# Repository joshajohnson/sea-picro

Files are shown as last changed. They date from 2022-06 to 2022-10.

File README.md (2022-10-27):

# Sea-Picro

Sea-Picro is a RP2040 based board in the Arduino Pro Micro form factor. Like [Sea-Micro](https://github.com/joshajohnson/sea-micro#sea-micro), it's designed to be a drop in replacement for keyboards wanting an upgrade from ATmega32u4 based pro micros.

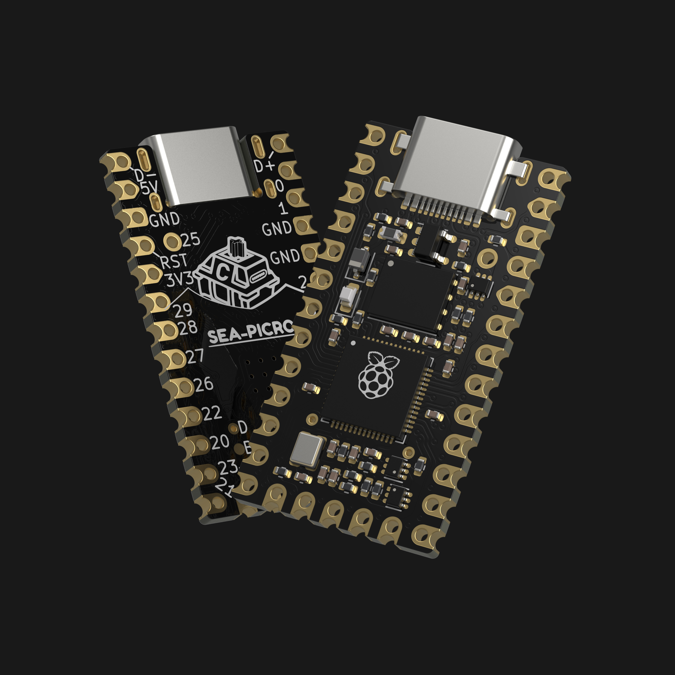
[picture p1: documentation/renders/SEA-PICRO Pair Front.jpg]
pcb render


There are two variants:
- EXT, featuring an Elite-C pinout, with dedicated 5V RGB LED pin, but without a reset button.
- RST, featuring a pro micro pinout, with onboard RGB LED and reset button.

Sea-Picro can be purchased from [CustomKBD](https://customkbd.com/).

### Sea-Picro EXT
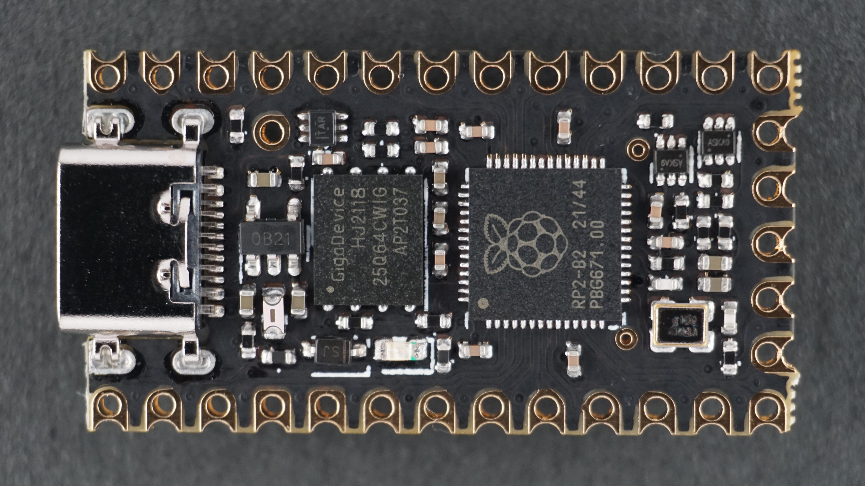
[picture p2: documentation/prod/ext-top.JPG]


### Sea-Picro RST
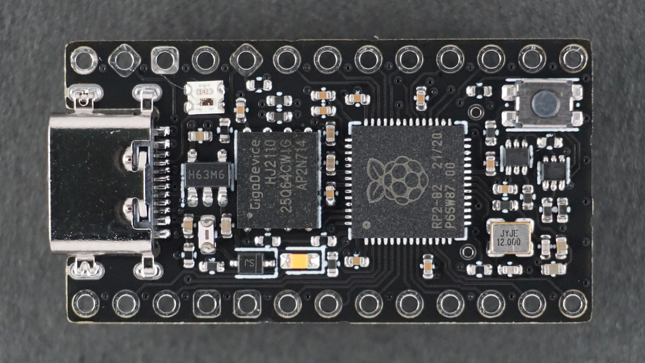
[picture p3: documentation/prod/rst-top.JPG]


## Features
- Compatiable with most pro micro based keyboards
- RP2040 microcontroller, with dual M0+ processors at up to 133MHz
- Mid mount USB-C connector, which is low profile and can't be ripped off
- Optional [Elite-C](https://deskthority.net/wiki/Elite-C) style pinout, adding an additional 5 IO for large keyboards
- Single button reset / bootloader circuit which changes behavior based on how long it's held (RP2040 usually requires two buttons to flash new firmware, making it challenging when installed upside down in a keyboard)
- ROM bootloader which prevents board from being bricked
- EXT version has a 5V level shifter and extra pin to drive strings of WS2812 LEDs.
- RST version has a WS2812 LED for use with CircuitPython or as a status indicator on the RST version. 
- Onboard power LED.
- IO pinout identical to the [Sparkfun RP2040 Pro Micro](https://www.sparkfun.com/products/18288)

## Pinout
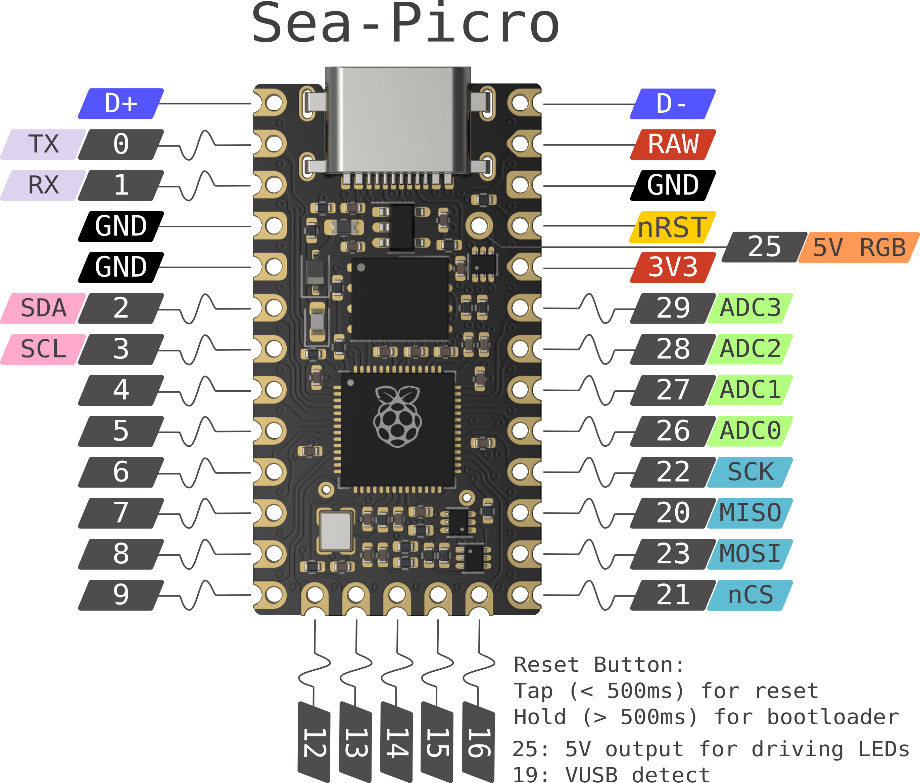
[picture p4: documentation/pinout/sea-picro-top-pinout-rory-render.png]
annotated pinout of PCB


## Documentation 

Documentation including flashing instructions can be found on [my website](https://www.joshajohnson.com/sea-picro/#documentation).

## One Button Reset / Bootloader Circuit

One of the tricky things with the RP2040 is that unlike the pro micro, to update the firmware you need to use two buttons in sequence to put it into the bootloader. To get around this, I've designed a circuit which when tapped for less than 500ms will reset the board, but when held for more than 1 second will jump into the bootloader. This makes life much easier for keyboards that install the microcontroller upside down, or have limited access to the reset buttons on the micro.

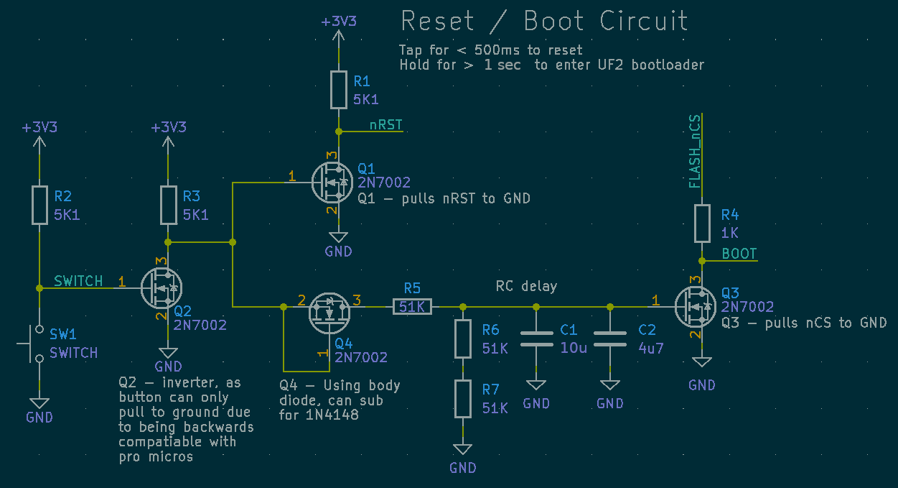
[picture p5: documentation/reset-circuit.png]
reset circuit schematic


## Revision History
- V1.0 increased the reset/bootloader decision time, along with DFM improvements and BOM fixes.
- V0.3 added castellated pads to the EXT version, along with changing the pinout to conform to the "BastardKB RP2040 Pinout". Numerous DFM improvements and bug fixes as per [#2](https://github.com/joshajohnson/sea-picro/issues/2).
- V0.2 added the one button reset / bootloader circuit, along with a number features and DFM improvements. Fixes [#1](https://github.com/joshajohnson/sea-picro/issues/1).
- V0.1 was more or less a clone of the Sparkfun RP2040, and was used as a refrence point for development. Tested and working, but not recomended for use.

## Contribuitors

- Michael Gard aka fig (@figthedevil / figurativelythedevil#4475) for adding castellated pads, teardrops, numerous DFM improvements, and feedback on the design.
- Ant from [CustomKBD](https://customkbd.com/) for the Sea-Picro artwork.
- ClassicRory ([Instagram](https://instagram.com/classicrory), [Discord](https://discord.gg/rNYgYDtyRp)) for the amazing renders of Sea-Picro.

## Contributing

If you want to download the project, ensure you clone `--recursive` as my parts library is pulled in as a submodule.

For any suggestions, areas of improvement, or problems you've found, please open an issue or pull request. I'm keen to make this board work for as many as people as possible, so please don't hesitate to suggest a change.

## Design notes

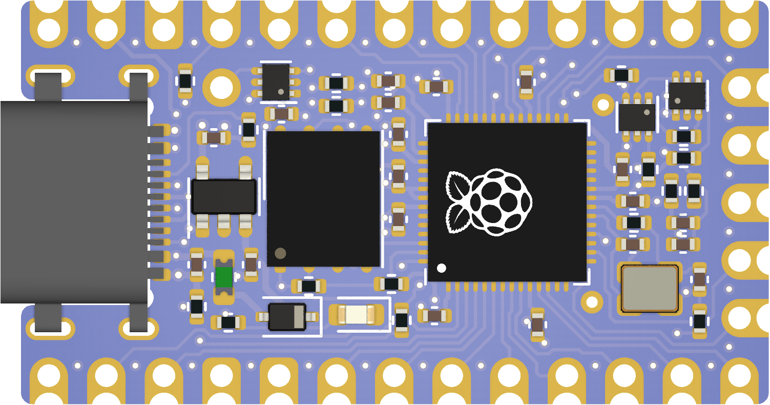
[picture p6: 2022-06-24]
documentation/pinout/images/sea-picro-top-no-back.png

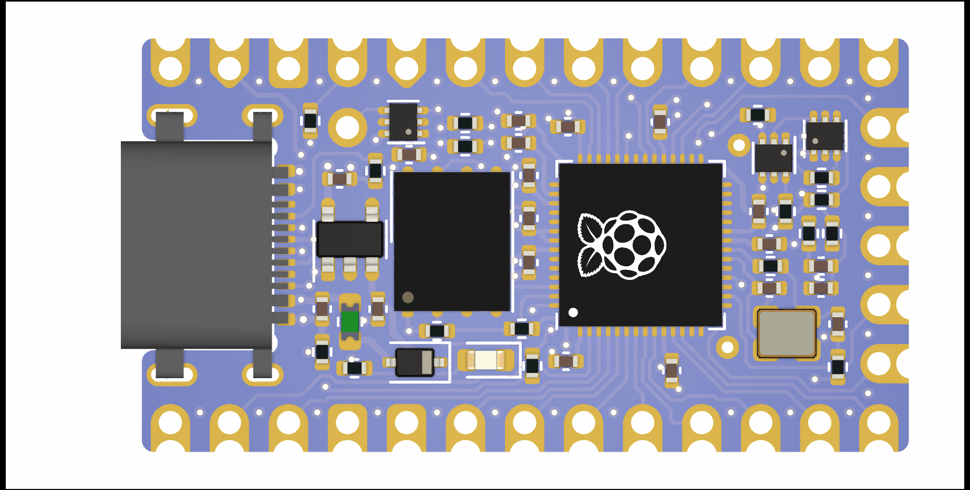
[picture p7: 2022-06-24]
documentation/pinout/images/sea-picro-top.png

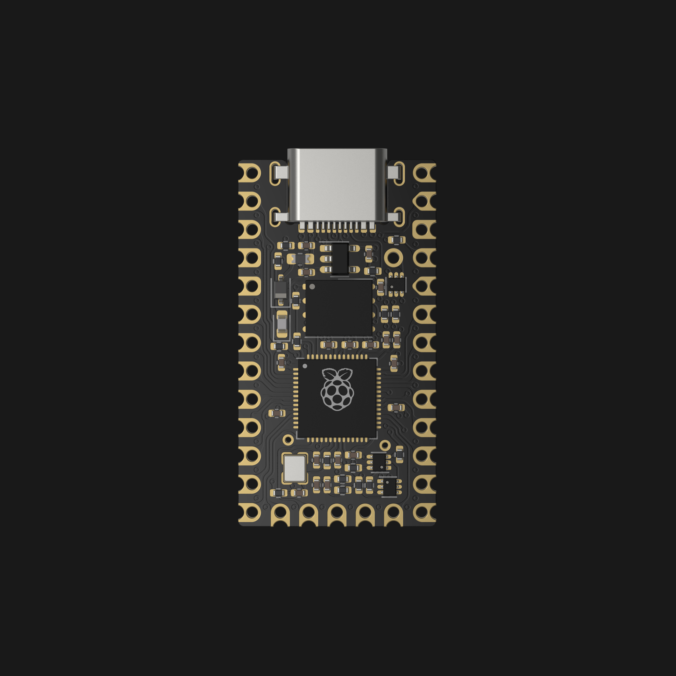
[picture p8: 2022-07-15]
documentation/pinout/images/SEA-PICRO-top-elevation-no-back.jpg

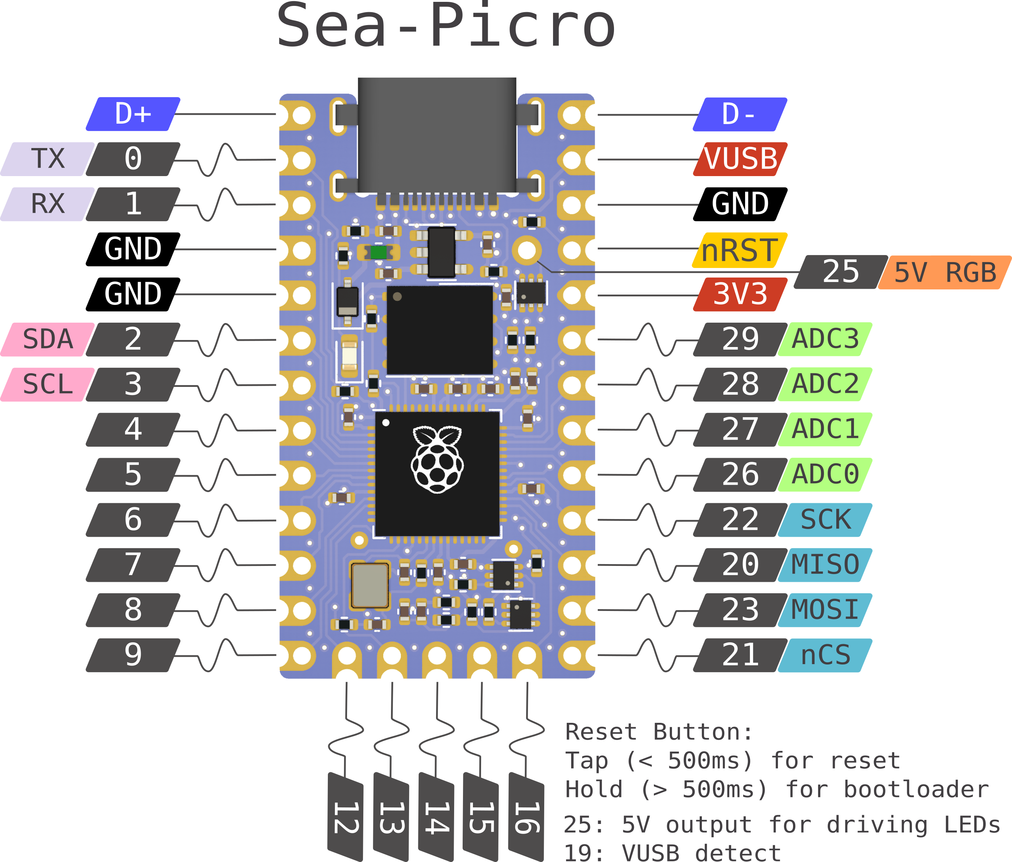
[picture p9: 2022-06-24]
documentation/pinout/sea-picro-top-pinout.png

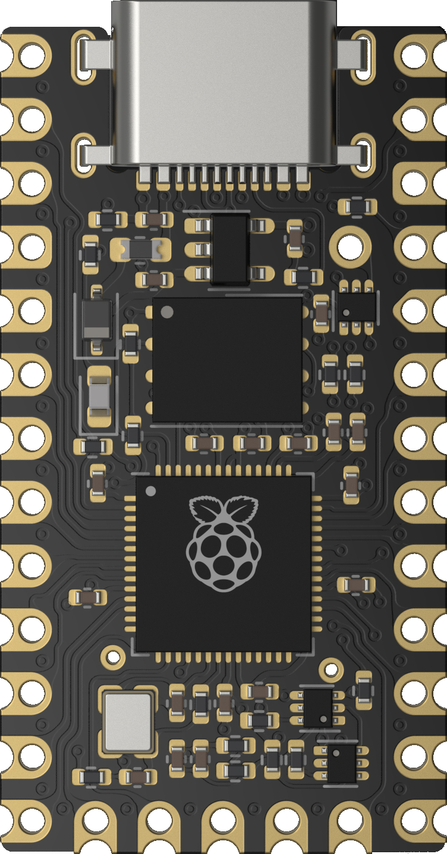
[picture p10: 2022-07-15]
documentation/pinout/SEA-PICRO-top-elevation-no-back.png

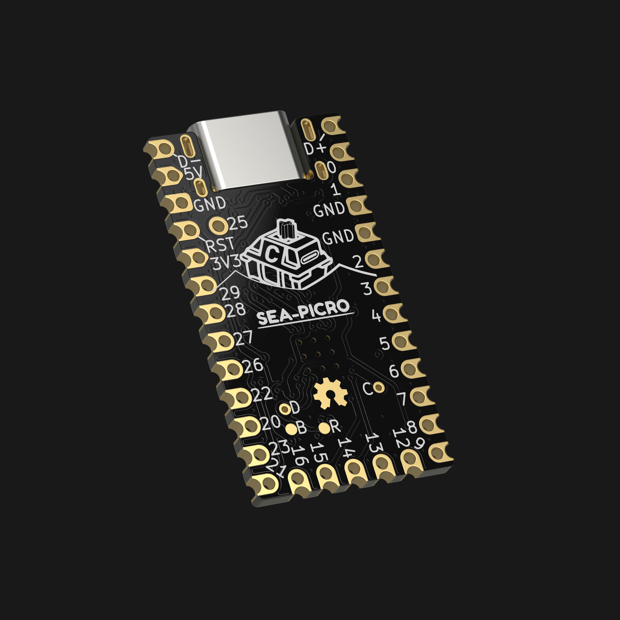
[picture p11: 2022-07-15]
documentation/renders/SEA-PICRO Rear Solo.jpg

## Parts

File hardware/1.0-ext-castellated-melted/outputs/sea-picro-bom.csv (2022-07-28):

Item | Qty | Reference(s) | Value | Footprint | JLC Basic | MPN | Manufacturer | LCSC | Substitute
1 | 4 | C1, C2, C3, C5 | 4u7 | Capacitor_SMD:C_0402_1005Metric | Y | CL05A475MP5NRNC | Samsung Electro-Mechanics | C23733 | Y
2 | 10 | C4, C8, C10, C11, C13, C14, C15, C16, C17, C18 | 100n | Capacitor_SMD:C_0402_1005Metric | Y | CL05B104KO5NNNC | Samsung Electro-Mechanics | C1525 | Y
3 | 2 | C6, C7 | 15p | Capacitor_SMD:C_0402_1005Metric | Y | 0402CG150J500NT | FH(Guangdong Fenghua Advanced Tech) | C1548 | Y
4 | 2 | C9, C12 | 1u | Capacitor_SMD:C_0402_1005Metric | Y | CL05A105KA5NQNC | Samsung Electro-Mechanics | C52923 | Y
5 | 1 | C19 | 10u | Capacitor_SMD:C_0402_1005Metric | Y | CL05A106MQ5NUNC | Samsung Electro-Mechanics | C15525 | Y
6 | 1 | D1 | B5817WS | josh-passives-smt:D_SOD-323 | N | B5817WS | Shikues | C122854 | N
7 | 1 | D2 | LED | LED_SMD:LED_0603_1608Metric | N | OSK40603C1E | OptoSupply | C268294 | Y - Any Pink
8 | 1 | F1 | 500mA | josh-passives-smt:Fuse_0603_1608Metric | N | MF-FSMF050X-2 | BOURNS | C210357 | Y
9 | 1 | J1 | USB_C_Receptacle_USB2.0 | josh-connectors:USB-C_MID_MOUNT_918-418K2024S40000 | N | 918-418K2024S40000 | Jing Extension of the Electronic Co | C168688 | Y
10 | 2 | Q1, Q2 | 2N7002VC-7 | josh-soic-sot-etc:SOT-563 | N | 2N7002V | Changjiang Electronics Tech (CJ) | C504145 | Y
11 | 8 | R1, R2, R4, R5, R6, R10, R12, R17 | 5K1 | Resistor_SMD:R_0402_1005Metric | Y | 0402WGF5101TCE | UNI-ROYAL(Uniroyal Elec) | C25905 | Y
12 | 2 | R3, R16 | 2K2 | Resistor_SMD:R_0402_1005Metric | Y | 0402WGF2201TCE | UNI-ROYAL(Uniroyal Elec) | C25879 | Y
13 | 2 | R7, R8 | 27R | Resistor_SMD:R_0402_1005Metric | N | 0402WGF270JTCE | UNI-ROYAL(Uniroyal Elec) | C25100 | Y
14 | 2 | R9, R15 | 1K | Resistor_SMD:R_0402_1005Metric | Y | 0402WGF1001TCE | UNI-ROYAL(Uniroyal Elec) | C11702 | Y
15 | 3 | R11, R13, R14 | 51K | Resistor_SMD:R_0402_1005Metric | Y | 0402WGF5102TCE | UNI-ROYAL(Uniroyal Elec) | C25794 | Y
16 | 1 | U1 | XC6210B332MR-G | josh-soic-sot-etc:SOT-23-5 | N | XC6210B332MR-G | Torex Semiconductor | C47719 | N
17 | 1 | U2 | GD25Q64CWIGR | josh-dfn-qfn:WSON-8-1EP_6x5mm_P1.27mm_EP3.4x4mm | N | GD25Q64CWIGR | GigaDevice Semicon Beijing | C395511 | N
18 | 1 | U3 | RP2040 | josh-dfn-qfn:RP2040-QFN-56 | N | RP2040 | Raspberry Pi | C2040 | N
19 | 1 | U4 | 74LVC1T45 | josh-soic-sot-etc:SOT-563 | N | SN74LVC1T45DRLR | Texas Instruments | C352970 | N
20 | 1 | Y1 | 12MHz | josh-oscillators:Crystal_SMD_2520-4Pin_2.5x2.0mm | N | 2TJ412000HYGBC | JYJE | C2149204 | N

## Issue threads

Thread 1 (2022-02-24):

r0.1 issues

joshajohnson, 2022-02-24:
- [x] WS2812B-2020 footprint is incorrect (rotated)
- [x] B3U-1000 buttons are expensive
- [x] Desirable to go into dfu mode with press of reset button (does not require holding BOOT whilst resetting)
- [x] DFM improvements if possible
- [x] Optimize for JLCPCB assembly if possible

Closed 2022-03-08.

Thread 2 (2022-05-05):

0.2 Errata

joshajohnson, 2022-05-05:
- [x] Update pinout to BastardKB RP2040 standard
~~- [ ] EXT has IO 12 mislabeled on the silk as 15~~
- [x] RST has R4 and R8 too close to each other
- [x] USB cutout needs DFM improvements, when routed with a large bit the drill holes don't create mickey mouse corners
- [x] More paste for mechanical legs USB C
- [x] EXT C5 and C19 are shorting at the top via during reflow
- [x] Crystal "floating", need to reduce paste area

joshajohnson, 2022-06-18:
Issues resolved in  e7286c6d610a8fc6a5dc470add58982169805a12

Closed 2022-06-18.

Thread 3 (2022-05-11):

firmware does not run

freznel10, 2022-05-11:
Josh, were you able to load qmk firmware successfully? I could get into the bootloader and load uf2, but could not get the firmware to run.

joshajohnson, 2022-05-12:
Discussing with @freznel10 in a different channel, we found flashing the circuit python UF2 then QMK did the trick.
Can't explain why that works but if anyone else gets the same issue it might be an approach to try.

Closed 2022-05-12.

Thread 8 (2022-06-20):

Pinout diagram isn't updated for latest IO

joshajohnson, 2022-06-20:
Needs to be updated, and include VBUS detection pin in drawing

joshajohnson, 2022-06-24:
fixed in [b8765c5](https://github.com/joshajohnson/sea-picro/commit/b8765c5cc1ce742b1422780b96b7cb3d1d4e9055)

Closed 2022-06-24.

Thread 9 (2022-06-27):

1uF cap in BOM is 0603 not 0402

joshajohnson, 2022-06-27:
need to fix in schematic and output BOM / iBOM

joshajohnson, 2022-06-27:
Fixed in [9d84a7a](https://github.com/joshajohnson/sea-picro/commit/9d84a7a4965da037a2cd5818e65fc158aedac178)

Closed 2022-06-27.

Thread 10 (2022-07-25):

v.03 test

freznel10, 2022-07-25:
Hi Josh, has v.3 been tested already? Sorry, I could not find the conversations tab hence I placed my question here.

joshajohnson, 2022-07-26:
Hey Freznel, it''s partially tested.

I've checked all the IO work, but need to check VBUS detection, RGB LED, check a few voltages, and a few other things.
If you can hold off for 48 hours I'll have finished testing and update here with (hopefully) good news.

freznel10, 2022-07-26:
Thank you!

On Tue, Jul 26, 2022 at 6:39 PM Josh Johnson ***@***.***>
wrote:

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

joshajohnson, 2022-07-27:
Hi @freznel10,

I assembled a few more boards and tested them, have found two more issues documented in https://github.com/joshajohnson/sea-picro/issues/11.

Will hopefully resolve by this time tomorrow assuming all goes well.

joshajohnson, 2022-07-28:
All tested now @freznel10!

I'm ordering a bunch of the 1.0 boards now, so fingers crossed there are no more bugs!

freznel10, 2022-07-28:
Nice to hear that!:) Hope everything turns out fine for the 1 boards!

Closed 2022-07-28.

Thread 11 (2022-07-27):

0.3 Errata

joshajohnson, 2022-07-27:
- [X] Footprint for D1 is on the small side - update with datasheet / IPC recommended footprint
- [X] Auto reset circuit is not waiting long enough to jump into bootloader on some boards - adjust components to extend charge time.

joshajohnson, 2022-07-27:
Yes correct - instead of the reset / bootloader point being at 500ms (approx), on one board it's closer to 200ms.
I can still get it to reset, but I just have to tap very quickly.
Should be fairly easy to fix, I just need to swap some parts and take measurements on a few boards to confirm consistent behaviour.

Interestingly I (nor any of the folks testing) have run into this so far, it's just one board on my desk. Maybe I populated a wrong component...

joshajohnson, 2022-07-28:
Fixed in 64acc074a7ae7dfcb6f1962cd64d2bc71366196c

Reset issue was resolved by moving a cap from 4u7 to 10u in the delay circuit.

Closed 2022-07-28.

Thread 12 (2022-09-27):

How does the reset/boot circuit work?

girishji, 2022-09-27:

joshajohnson, 2022-09-27:
Hi,

The README explains its function per below.

> When tapped for less than 500ms will reset the board, but when held for 500ms or more will jump into the bootloader.

You can also find the LTspice simulation in the simulation folder.-------- Original Message --------
On 28 Sept 2022, 04:17, girish wrote:

> —
> Reply to this email directly, [view it on GitHub](https://github.com/joshajohnson/sea-picro/issues/12), or [unsubscribe](https://github.com/notifications/unsubscribe-auth/AHCIMJKCRJQ6ENMO5VXC3KDWAM235ANCNFSM6AAAAAAQXBGPUQ).
> You are receiving this because you are subscribed to this thread.Message ID: ***@***.***>

girishji, 2022-09-28:
I understand the usage. Is there a write up somewhere (reference) how this circuit works in principle? It is not intuitive how these mosfet switches cause delay.

joshajohnson, 2022-09-28:
R2, R3, and Q2 are to invert the active low signal of a pro micro for backwards compatibility. I have since realised that Q2 and R2 can be removed and SW1 placed where Q2 is.

R1 pulls nRST (RUN) high to enable the chip, and Q1 pulls it low to got into reset when Q2 turns off / SW1 is pressed.

For the delay circuit we need Q3 as the BOOT pin is also flash chip select, so if we had capacitance on that line the flash would never work.
R4 is probably not needed, but I never like pulling anything directly to ground.
The delay circuit could be made with 3 parts instead of 5, but I wanted to keep BOM lines low.

Q4 (could sub for a diode) is to ensure the gate of Q3 stays charged once you release the button - ensuring reset comes up before BOOT.

girishji, 2022-09-29:
When SW1 is not pressed you have 3v3 connected to 5k+3*51k resistors, resulting in 20 ma current drained continuously, no?
Also, is the RC delay circuit tested with components (not simulation)? RC delay is a good idea for this application.

joshajohnson, 2022-09-29:
I've manufactured and tested over 100 boards, so yes it's proven in real life.

It draws 600uA in the unpressed state.

Closed 2022-12-07.

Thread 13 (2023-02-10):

Reset sea picro

soulsoiledit, 2023-02-10:
I'm worried that I've bricked my EXT board while copying a new circuitpython .uf2 file over to the board. The device no longer shows up when plugged in, and trying to enter the bootloader mode does not work either. It did work prior to copying the circuitpython file.

Is there any solution?

soulsoiledit, 2023-02-10:
I have solved this issue by directly shorting the ground and reset pins rather than using the pads where the reset button would be. Shorting the pins while plugging in the board made it show up and enter bootloader mode.

Sorry for the trouble!

Closed 2023-02-10.

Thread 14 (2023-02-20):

Bootloader Mode

3rdPhalanx, 2023-02-20:
I've been trying to enter the bootloader mode by holding the reset button or shorting the reset and ground pins, and by doing so while shorting or holding reset and connecting it to the computer (Windows 11). I've tried this without a problem on a second sea-picro and it worked successfully. I've found that the sea-picro is detected as an HID/USB but does not appear as a mass storage device. I've tried to uninstall drivers for the device but am not really sure if what I've done is correct.

Any help is appreciated, Thank you

joshajohnson, 2023-02-21:
Hi, it sounds like the board might be defective as shorting RST whilst plugging the board in should cause it to go into bootloader like on your other board.

You can try shorting the "B" test point on the back of the board to GND whilst plugging it in to bypass the reset circuit, and hopefully with that being held low it'll go into bootloader mode.

Was this a unit you hand assembled or purchased from somewhere?

3rdPhalanx, 2023-02-21:
This is 1 of 2 boards that I bought for a sofle build, but I actually already tried the b pin on the back since it's already been soldered on, and was unsuccessful. If it's defective then I'll just contact the seller again thank you

Great board by the way

joshajohnson, 2023-02-21:
Ah bugger, would have been nice to get it working again.

Out of interest where was the unit purchased from?
All of the units I've sold to vendors have been tested before leaving my bench, so if it's one of those units I'd be keen to get it back and see where the test procedure has failed to allow a faulty board to escape.

3rdPhalanx, 2023-02-21:
I ordered it from Beekeeb as a part of a sofle kit.

joshajohnson, 2023-02-21:
Thanks, that's not a unit I've tested so I'd suggest the best course of action would be reaching out to them and asking for assistance.

kamaaina, 2024-03-10:
came across this post, and funny thing is, i have the same behavior with *both* of my sea picro's. i bought the ferris sweep kit from beekeeb.  i will try to contact him as well.

like @3rdPhalanx, i soldered my controller to the pcb, but i tried shorting the ground and reset as well as pressing the reset button and both did not work.

idank, 2024-04-08:
> came across this post, and funny thing is, i have the same behavior with _both_ of my sea picro's. i bought the ferris sweep kit from beekeeb. i will try to contact him as well.
>
> like @3rdPhalanx, i soldered my controller to the pcb, but i tried shorting the ground and reset as well as pressing the reset button and both did not work.

This sounds like a manufacturing error. I have gone through many sea picros (produced at JLC and Elecrow) and some small percentage of them will either not boot straight from the fab house, or will fail after soldering headers to them, or have a gpio fail, etc etc. I haven't been able to figure out what causes this (it doesn't seem to be a soldering issue on the picro itself), but my understanding is that without a custom test suite at the fab house that checks for specific fault points, this is expected past a certain scale of production.

Closed 2023-02-21.

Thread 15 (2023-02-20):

Sea Picro maybe bricked?

third774, 2023-02-20:
I ordered a [Chocofi kit](https://shop.beekeeb.com/product/chocofi-36-keys-kailh-low-profile-choc-v1-mechanical-ergonomic-hotswap-split-keyboard-diy-kit/) that included two [Sea Picro](https://github.com/joshajohnson/sea-picro) microcontrollers and am running into issues getting the firmware installed and working.

When I first plugged them in, my Mac (running 13.1 Ventura) recognized them as a USB storage device. I was trying to use the [QMK toolbox](https://github.com/qmk/qmk_toolbox) to flash the firmware onto them, not realizing that I needed to drag and drop a `.uf2` file instead of trying to flash a `.hex` file.

In the process of figuring that out, I had pressed the reset button a bunch of times and would see a message from MacOS saying I hadn't properly ejected the device, so I was pretty sure that the reset button was working correctly, but just to be sure I tried shorting the reset and ground pins and saw the same behavior.

I decided to just try putting the `.uf2` file on the [docs page here](https://docs.beekeeb.com/chocofi-keyboard) and after I did this for each half of the keyboard, the MacOS keyboard setup prompt did appear, but I was not able to proceed with it because the button to proceed was disabled waiting for me to press a key on the keyboard. I tried pressing keys on the board, but nothing happened. So I closed out of that, and now the Sea Picro no longer shows up as a USB device in Finder.

It does show up in System Information, and when I run:

```sh
> system_profiler SPUSBDataType

USB:

    USB 3.1 Bus:

      Host Controller Driver: AppleT6000USBXHCI

        Corne:

          Product ID: 0x0001
          Vendor ID: 0x4653
          Version: 0.01
          Serial Number: vial:f64c2b3c
          Speed: Up to 12 Mb/s
          Manufacturer: foostan
          Location ID: 0x01100000 / 1
          Current Available (mA): 500
          Current Required (mA): 500
          Extra Operating Current (mA): 0
```

[Supposedly this board can't be bricked](https://github.com/joshajohnson/sea-picro#features), but it seems to have done it? I've tried:
- Pressing the reset button once
- Pressing the reset button twice quickly
- Holding the reset button for a few seconds
- Holding the reset button for a long time
- Holding the reset button while plugging it in.
- Using different USB ports on my MacBook
- Rebooting
- Using a different MacBook
- Using a Surface Pro 10
- Lots of searching online

Any ideas on what to try next would be super appreciated. I'm also looking into getting openocd set up to see if I can reset the board over USB connection somehow, but running into issues with that as well.

FWIW, I'm pretty confident that I didn't mess up any soldering with the board and header pins so I don't think anything shorted to brick the board apart from me shorting the reset pin, but that seemed to give the same behavior as the reset button, and I was able to put files on it once.

joshajohnson, 2023-02-21:
Hi,

Given the board enumerates I'd have to assume it's not bricked and instead is not getting into the bootloader.

Holding the reset button down / shorting the RST button to GND whilst inserting should bring the device into it's ROM bootloader.

If that's not happening, can you try shorting the "B" test point on the back of the board to GND whilst plugging it in which skips the reset button to force it into bootloader mode.

If the RP2040 hadn't been flashed before you got it, it would first enumerate in the bootloader and allow you to flash the `.uf2` file, but if the reset circuit is not working correctly it would not allow you to get back into the bootloader.

If after trying the above the issue continues, I'd suggest reaching out to the place your purchased Sea-Picro from and ask for confirmation all of the features were tested before shipping to ensure the unit shipped to you isn't defective.

third774, 2023-02-21:
Thanks! Turns out I installed the micro controller facing the wrong direction. Apparently these are the symptoms. 🙈

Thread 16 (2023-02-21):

make new fails

idank, 2023-02-21:
Trying to build the gerbers locally, I'm getting:

```
$ make new
git submodule update --init --recursive --progress
Submodule path 'josh-kicad-lib': checked out 'ef4384a867d9c2ea6f2b9b7983db1512670b1de6'
cd josh-kicad-lib && git checkout master && git pull
Previous HEAD position was ef4384a dfm for sea-picro
Switched to branch 'master'
Your branch is up to date with 'origin/master'.
Already up to date.
cd josh-kicad-lib && bash setup.sh "1.1" "idank" "Josh Johnson"
sed: 1: "../hardware/1.1/idank.k ...": invalid command code .
sed: 1: "../hardware/1.1/idank.k ...": invalid command code .
+++ DONE
```

Did I miss a step? Also I'm no Make expert but where are these rules defined?

```
prod-files:
	make gerb
	make pnp
	make bom
```

Are there ready to go gerbers/cpl files out there so I don't have to build locally?

Thanks!

joshajohnson, 2023-02-21:
That might be old code that I forgot to delete...

Gerbers are in the [releases](https://github.com/joshajohnson/sea-picro/releases) section.

idank, 2023-02-21:
Nice, thanks. Do you happen to also have CPL files for JLC?

idank, 2023-02-21:
Never mind, I converted the .pos file.

Closed 2023-02-21.

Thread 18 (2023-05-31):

Prone to shorts with split keyboards?

idank, 2023-05-31:
There's been some talk in discord that the sea picro / RP2040 is prone to shorts when used in split keyboards. Apparently this happens when the TRRS cable between halves is disconnected while the main side is still USB powered. I've personally experienced this once but can't be 100% sure I did exactly that.

Is this a known issue with sea picro, the RP2040 chip, or completely unknown to you?

idank, 2023-05-31:
p.s. not sure "short" is the correct term here, someone referred to this as hot plugging.

joshajohnson, 2023-06-01:
I'm not quite sure what you mean.

I understand that plugging / unplugging TRRS cables whilst still connected to USB can cause shorts (as the terminals are all exposed) but that has nothing to do with the selected controller.

Are you saying that if you short out the cable it'll kill one of the controllers?
If so what side dies and is there any visible damage?

I haven't heard of this issue, or anything similar before so if it's something we can identify and resolve that'd be great.

idank, 2023-06-01:
No not shorting anything by hand, just plugging / unplugging the trrs cable when USB is connected. Presumably the serial pin on the main side gets killed. This seems specific to sea picro as I've never had this happen on cheap pro micros.

Sadly I don't have the faulty picro anymore. I'll be getting more in a few weeks so I might be able to stress test this.

joshajohnson, 2023-06-01:
Ah yeah, the serial pin being killed is what you'd expect if you shorted 5V to a 3V3 IO like the RP2040 uses.
This isn't specific to Sea-Picro, it would be common with any microcontroller running at 3V3 (RP2040, STM32, etc).

Assuming it's an IO failure it's not something we'd visually be able to notice, you'd have to de-encapsulate the IC and look at it under a microscope to confirm.

idank, 2023-06-01:
Seeing as this is pretty common procedure when dealing with split keyboards, is it possible to protect against this within the sea picro?

joshajohnson, 2023-06-01:
Not really, the simple fix is to unplug the keyboard from power before connecting / disconnecting which is recommend for any controller.

idank, 2023-06-01:
Roger that, thanks for your work.

Closed 2023-06-01.

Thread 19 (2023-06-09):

5V on pin 25

idank, 2023-06-09:
Hey, not sure if I'm misunderstanding things, but should I be getting 5V between pin 25 and GND? I'm trying to drive the Pimoroni trackball and getting some flaky performance off the 3.3v pin, so I figured I'd try pin 25 but that doesn't seem to work so I must be doing something stupid.

joshajohnson, 2023-06-09:
Hi, no you should not be getting 5V from this pin - it's a digital output designed for powering LEDs.

You'll want to use the "RAW" pin, as this will provide you with 5V.

idank, 2023-06-09:
Duh, silly of me! Thanks so much.

Closed 2023-06-09.

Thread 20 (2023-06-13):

I2C woes

idank, 2023-06-13:
Hey Josh,

I've been having some weird issues with a [trackball i2c device](https://shop.pimoroni.com/products/trackball-breakout?variant=27672765038675). I've used dozens of this on generic pro micros just fine, but for some reason it doesn't work quite right with the sea picro.

There's some apparent spikes during big moves as seen here: https://i.imgur.com/9OhksMT.mp4 (starts around the 5 second mark). It doesn't seem to be firmware related (I looked at the raw i2c reads in QMK, they're just bigger when the spikes occur). Nor is the trackball unit itself at fault as it works fine when wired to a pro micro.

The only evidence I've found of this being an issue specific to the RP2040 is https://github.com/arduino/ArduinoCore-mbed/issues/448, but I don't have the tools or knowledge to test this out.

Do you have any thoughts on this? Thanks.

joshajohnson, 2023-06-13:
That's strange behavior, I've used the bare trackball before but not that module.

It would be ideal to get a logic analyser trace of what is going on, my guess is that a read is failing and by the time the next read works it's got a large delta which results in the jumpy behaviour.

I doubt that Arduino issue is relevant, as it's not used in QMK.

Looking at the example code [here](https://github.com/pimoroni/pimoroni-pico/blob/main/examples/breakout_trackball/demo.cpp), it calls out that I2C needs to be less than 100KHz, I wonder what it's set to in QMK?

Otherwise the next step would be getting an oscilloscope / logic analyser on the bus and seeing that there is decent signal integrity, correct clock speed, and looking at the raw packets flying around.

Sadly purchasing those trackballs in Australia are quite expensive, so it's not something I'll be able to source to assist with debugging.

idank, 2023-06-13:
From the [product page](https://shop.pimoroni.com/products/trackball-breakout?variant=27672765038675):

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

and it seems the default in [QMK](https://docs.qmk.fm/#/i2c_driver?id=avr-configuration) is 400k, but even after lowering it to 250k, 100k, I'm still getting spikes. :(

idank, 2023-06-15:
Well this is embarrassing. Apparently when QMK is running in split keyboard mode, it'll check for connectivity with the slave side every few second, and these spikes occur whenever the check is happening. I was testing things out with just one side connected. 🤦

joshajohnson, 2023-06-16:
That's not what I expected the issue to be, but nice work figuring it out!

Closed 2023-06-15.

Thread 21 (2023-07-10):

D2 alternative?

idank, 2023-07-10:
It seems JLCPCB is always out of the component for D2 (C268294). It's possible to order specific parts for PCBA but figured I'd ask before doing so if there's a suggested alternative one?

joshajohnson, 2023-07-11:
Any 0603 LED is suitable.

idank, 2023-07-13:
Thanks.

Looks like Q1,Q2 are out of stock too, is [this](https://jlcpcb.com/parts/compare/111721,516804) a good replacement (right side is BOM)?

joshajohnson, 2023-07-14:
Yep that looks suitable.

Closed 2023-07-11.

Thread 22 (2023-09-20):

Flash chip doesn't match QMK's default

idank, 2023-09-20:
I recently tried my first PCBA order from JLC and upon flashing QMK realized (with the help of the kind folks on discord) that it's configured for a different flash chip than the one in bom, as seen here: https://docs.qmk.fm/#/platformdev_rp2040?id=rp2040-second-stage-bootloader-selection.

It only takes one define to get working, but figured that you might want to document this or perhaps even change the flash in the bom to W25Q080 so folks don't have to deal with this to begin with, seeing as the picro is most commonly used with QMK.

joshajohnson, 2023-09-20:
Fixed in https://github.com/joshajohnson/joshajohnson.github.io/commit/b7dc95860029295b421f1e27cc69c6d4512357c7

idank, 2023-09-21:
Out of curiosity are the two interchangeable on the sea picro, or would other components need to be changed as well?

joshajohnson, 2023-09-22:
They are interchangeable.

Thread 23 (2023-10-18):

version with all pins exposed

alextwothousand, 2023-10-18:
I like the sea picro footprint quite a lot, but I was wondering if there was a version with all the pins exposed. Many thanks.

WainingForests, 2024-05-14:
@joshajohnson Not to steal the topic, but I've been considering building a 'sea picro' esk design for keyboards that is built into the board.

I've found Winbond Elec W25Q16JVUXIQ flash to be reasonably cheap and a smaller overall footprint!
Hardware design I'm pretty alright on regarding circuit design, but do you think I'll be able to flash the board with your [circuitpy-sea-picro.uf2](https://github.com/joshajohnson/sea-picro/releases/download/v1.0/circuitpy-sea-picro.uf2) and have it accept the 16mb flash, along with more / all of the rp2040 raw pins exposed?

The idea was to use it with KMK / QMK keyboards.

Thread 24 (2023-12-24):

mismatch between sea picro's kicad footprints and actual PCB?

idank, 2023-12-24:
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

The yellow outline is from sea-picro:Sea-Picro_EXT_Through_Hole_Flipped and is slightly inset from the actual edge cut of the 1.0-ext pcb. The through holes do match correctly. I haven't checked the other pcb styles.

It's not a huge difference but can cause issues when wanting the sea picro to be mounted precisely on other pcbs.

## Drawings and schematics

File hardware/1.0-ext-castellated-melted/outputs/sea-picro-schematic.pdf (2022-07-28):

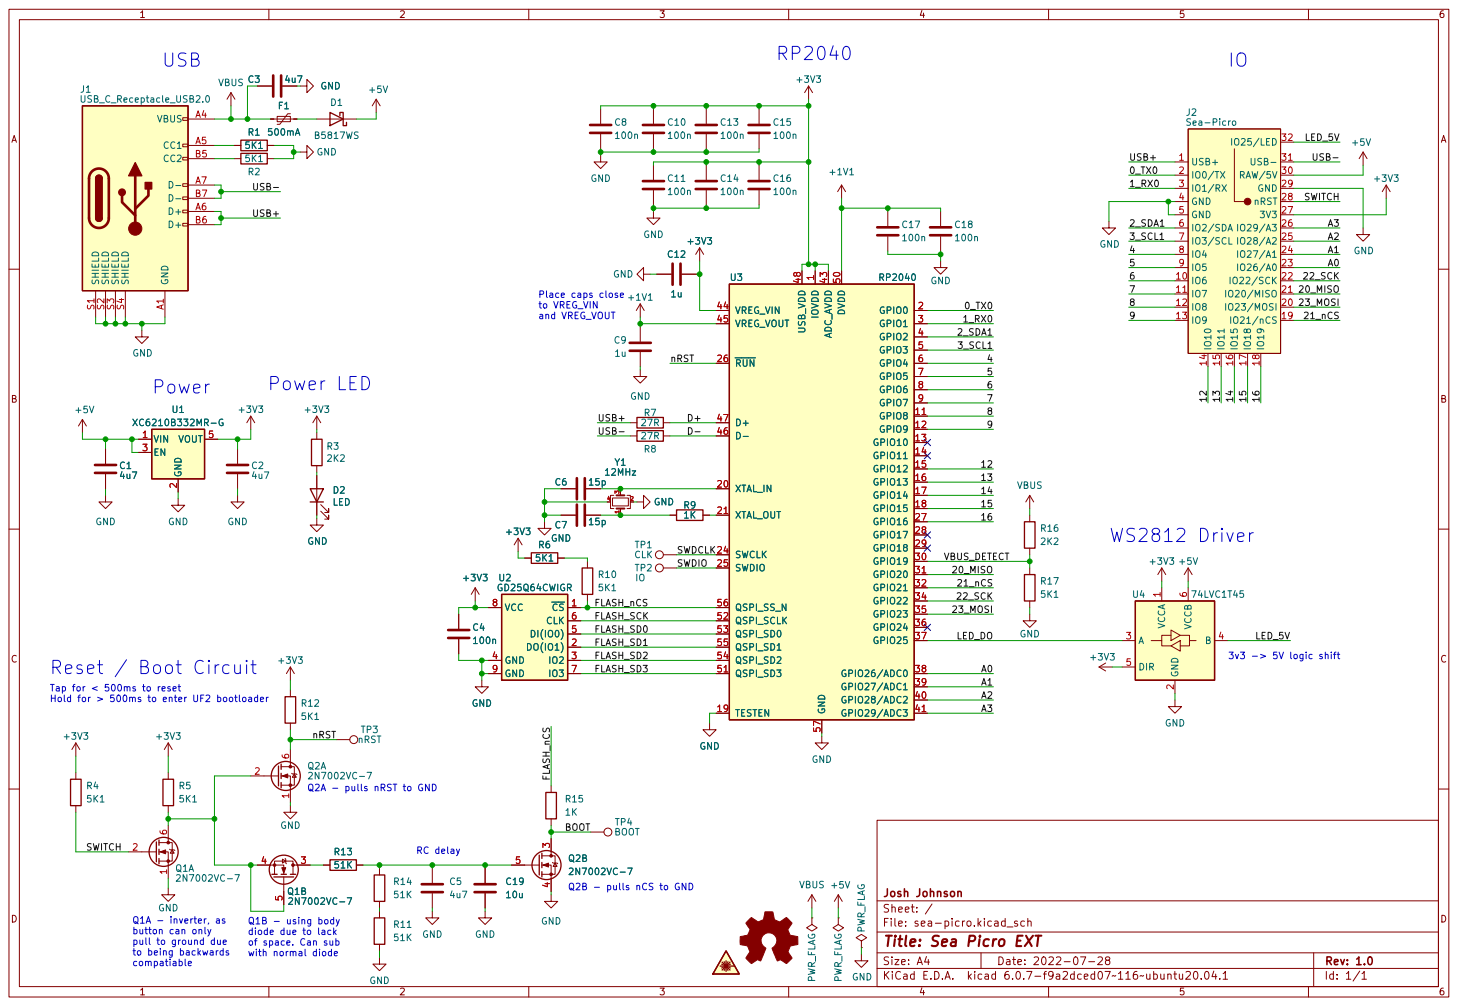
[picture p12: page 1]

Power Q1A - inverter, as button can only

1 GPIO8 11 GPIO9 12 GPIO10 13 GPIO11 14 GPIO12 15 GPIO13 16 GPIO14 17 GPIO15 18 TESTEN 19 GPIO0 2 XTAL_IN 20 XTAL_OUT 21 SWCLK 24 SWDIO 25 ~{RUN} 26 GPIO16 27 GPIO17 28 GPIO18 29 GPIO1 3 GPIO19 30 GPIO20 31 GPIO21 32 GPIO22 34 GPIO23 35 GPIO24 36 GPIO25 37 GPIO26/ADC0 38 GPIO27/ADC1 39 GPIO2 4 GPIO28/ADC2 40 GPIO29/ADC3 41 ADC_AVDD 43 VREG_VIN 44 VREG_VOUT 45 D- 46 D+ 47 USB_VDD 48 GPIO3 5 DVDD 50 QSPI_SD3 51 QSPI_SCLK 52 QSPI_SD0 53 QSPI_SD2 54 QSPI_SD1 55 QSPI_SS_N 56 GND 57 GPIO4 6 GPIO5 7 GPIO6 8 GPIO7 9 U3 RP2040 R10

1 GPIO8 11 GPIO9 12 GPIO10 13 GPIO11 14 GPIO12 15 GPIO13 16 GPIO14 17 GPIO15 18 TESTEN 19 GPIO0 2 XTAL_IN 20 XTAL_OUT 21 SWCLK 24 SWDIO 25 ~{RUN} 26 GPIO16 27 GPIO17 28 GPIO18 29 GPIO1 3 GPIO19 30 GPIO20 31 GPIO21 32 GPIO22 34 GPIO23 35 GPIO24 36 GPIO25 37 GPIO26/ADC0 38 GPIO27/ADC1 39 GPIO2 4 GPIO28/ADC2 40 GPIO29/ADC3 41 ADC_AVDD 43 VREG_VIN 44 VREG_VOUT 45 D- 46 D+ 47 USB_VDD 48 GPIO3 5 DVDD 50 QSPI_SD3 51 QSPI_SCLK 52 QSPI_SD0 53 QSPI_SD2 54 QSPI_SD1 55 QSPI_SS_N 56 GND 57 GPIO4 6 GPIO5 7 GPIO6 8 GPIO7 9 GND

Q1B - using body diode due to lack of space. Can sub with normal diode Q2A - pulls nRST to GND

Q2B - pulls nCS to GND

File: sea-picro.kicad_sch Sheet: / Josh Johnson

Id: 1/1 Title: Sea Picro EXT

pull to ground due
to being backwards
compatiable

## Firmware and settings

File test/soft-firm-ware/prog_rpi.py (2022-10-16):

# System imports
import RPi.GPIO as GPIO
import time
import sys
import os
from colorama import Fore
import serial
from serial.tools import list_ports
import usb.core

# Local imports
sys.path.append("rpi-lib")
from sp_io import *
from adc import *
from shift_reg import *
from sp_serial import *
from oled import *

GPIO.setwarnings(False)
GPIO.setmode(GPIO.BCM)

RST  = 17
EXT  = 23
dut_type = None
# Map between IO position on Sea-Picro and location in shift reg chain
IO_TO_SR_MAP = [15, 16, 17, 18, 19, 20, 21, 22, 7, 8, 14, 0, 1, 2, 3, 4, 5, 6, 9, 10, 11, 12, 13]
# IO list of SP in same order as above
SP_PIN_MAP = ["D0", "D1", "D2", "D3", "D4", "D5", "D6", "D7", "D8", "D9", "D21", "D23", "D20", "D22", "D26", "D27", "D28", "D29", "D12", "D13", "D14", "D15", "D16"]

# USB strings
RPI_VID = 0x2e8a
RPI_PID = 0x0003

CPY_VID = 0x6a6a
CPY_PID = 0x5350

global fail_str
fail_str = ""

def flash_circuitpython():
    ''' Flashes circuitpython firmware. '''
    global fail_str
    test_fail = True
    found_rpi = False
    attempt_counter = 0
    # Spinlock until RPi bootloader is found
    while found_rpi == False:
        print(f"{Fore.BLUE}Searching for RP2040 bootloader")
        dev = usb.core.find(find_all=1)
        for cfg in dev:
            if cfg.idVendor == RPI_VID and cfg.idProduct == RPI_PID:
                found_rpi = True
        time.sleep(1)
        attempt_counter = attempt_counter + 1
        if attempt_counter > 5:
            print(f'{Fore.RED}TIMEOUT TRYING TO FIND BOOTLOADER!')
            fail_str = "CPY"
            test_fail = True
            break

    if found_rpi:
        print(f"{Fore.BLUE}Bootloader found, copying CircuitPython")
        oled_write("Flashing CPY")
        time.sleep(3)
        retval = os.system("cp circuitpy-sea-picro.uf2 /media/pi/RPI-RP2")
        if retval != 0:
            print(f'{Fore.RED}FAILED TO FLASH CIRCUITPYTHON!')
            fail_str = "CPY"
            test_fail = True
        else:
            test_fail = False

    return test_fail

def flash_firmware():
    ''' Flashes test firmware. '''
    global fail_str
    test_fail = True
    found_cpy = False
    attempt_counter = 0
    # Spinlock until circuitpython is found
    while found_cpy == False:
        print(f"{Fore.BLUE}Searching for Circuitpython")
        dev = usb.core.find(find_all=1)
        for cfg in dev:
            if cfg.idVendor == CPY_VID and cfg.idProduct == CPY_PID:
                found_cpy = True
        time.sleep(1)
        
        attempt_counter = attempt_counter + 1
        if attempt_counter > 15:
            print(f'{Fore.RED}TIMEOUT TRYING TO FIND CIRCUITPYTHON!')
            fail_str = "FW"
            test_fail = True
            break

    if found_cpy:
        print(f"{Fore.BLUE}CircuitPython found, copying test firmware")
        oled_write("Flashing Test FW")
        time.sleep(5)
        retval = os.system("cp -rf circuitpy-files/* /media/pi/CIRCUITPY")
        if retval != 0:
            print(f'{Fore.RED}FAILED TO FLASH TEST FIRMWARE!')
            fail_str = "FW"
            test_fail = True
        else:
            test_fail = False
            sp_reset()
            time.sleep(3)

    return test_fail

def test_ident():
    # Check we have the right /dev/ttyACM port
    global fail_str
    test_fail = True
    send_dut_string("ident")
    ret_str = get_dut_string()

    if ret_str == "ident = Sea-Picro!":
        print(f'{Fore.BLUE}IDENT passed')
        test_fail = False
    else:
        print(f'{Fore.RED}IDENT Failed, possibly wrong /dev/ttyACM port')
        fail_str = "IDENT"
        test_fail = True

    return test_fail

def test_vbus():
    # Check VBUS detection
    global fail_str
    test_fail = True
    send_dut_string("vbus_test")
    ret_str = get_dut_string()

    if ret_str == "vbus = high":
        print(f'{Fore.BLUE}VBUS detect passed')
        test_fail = False
    else:
        print(f'{Fore.RED}VBUS detect failed')
        fail_str = "VBUS"

    return test_fail

def test_led():
    # RGB test time
    global fail_str
    test_fail = True
    print(f'{Fore.YELLOW}Monitor LEDs please')
    send_dut_string("led_rgb")
    
    print(f'{Fore.YELLOW}Did LEDs cycle R/G/B? YES / NO {Fore.WHITE}')
    oled_write("LEDs R/G/B?")
    time.sleep(1) # delay long enough that the operator has seen all colours work

    while True:
        if (not io_read(SW_YES)):
            print(f'{Fore.BLUE}RGB LEDs passed')
            test_fail = False
            send_dut_string("led_off")
            time.sleep(0.1)
            break
        if (not io_read(SW_NO)):
            print(f'{Fore.RED}RGB LEDs failed')
            send_dut_string("led_off")
            time.sleep(0.1)
            fail_str = "RGB"
            break

    return test_fail

def test_cc():
    global fail_str
    cc_val = adc_read("CC")

    if cc_val < 3000:
        print(f'{Fore.BLUE}CC pin passed')
        return False
    else:
        print(f'{Fore.RED}CC pin failed')
        fail_str = "CC"
        return True

def test_io(model):
    global fail_str
    test_fail = False
    for pos in range(0, model):
        shift_out((1 << IO_TO_SR_MAP[pos]))
        send_dut_string("io_test")
        ret_str = get_dut_string()

        array = ret_str[1:-1].split(", ") # Convert to array of strings "True", "False"

        key_fail = False # Used to flag if a key passes it's test or not

        # Loop through array and check val = False unless index == pos
        for index in range(0,model):
            # Case where we expect a key to be pressed
            if index == pos:
                if array[index] == "True":
                    pass
                else:
                    print(f'{Fore.RED}{SP_PIN_MAP[pos]}: IO {SP_PIN_MAP[index]} was NOT pressed')
                    key_fail = True
                    test_fail = True

            # Case where we do not expect a key to be pressed
            elif index != pos:
                if array[index] == "False":
                    pass
                else:
                    print(f'{Fore.RED}{SP_PIN_MAP[pos]}: IO {SP_PIN_MAP[index]} WAS pressed')
                    key_fail = True
                    test_fail = True

        if not key_fail:
            print(f'{Fore.BLUE}{SP_PIN_MAP[pos]}: IO {SP_PIN_MAP[pos]} passed')

        if test_fail:
            fail_str = "IO"

    return test_fail

def test_dut(model):

    test_fail = False
    oled_write("Testing DUT")
    # Don't continue testing if we can't ident properly
    if test_ident():
        return True

    test_fail = test_fail | test_vbus()
    test_fail = test_fail | test_cc()
    test_fail = test_fail | test_io(model)
    test_fail = test_fail | test_led()

    return test_fail 

# Init all the things!
io_init()
adc_init()
shift_reg_init()
oled_init()

time.sleep(1)
retest = False
test_only = False
# Super loop time
while True:
    if not retest:
        print(f"{Fore.YELLOW}Press YES to begin test!")
        oled_write("Begin Test?", size=20)
    retest = False
    while True:
        # try:
            if (not io_read(SW_YES) or test_only):
                time.sleep(0.1) # Shitty debounce
                led_reset()
                print(f"{Fore.BLUE}Beginning test!")
                test_fail = False

                # Configure tester for EXT or RST
                if (not io_read(SW_EXT_RST)):
                    print(f"{Fore.BLUE}Sea-Picro EXT selected")
                    oled_write("Testing EXT")
                    dut_type = EXT
                else:
                    print(f"{Fore.BLUE}Sea-Picro RST selected")
                    oled_write("Testing RST")
                    dut_type = RST

                # Check if we need to flash cpy or not
                if (not io_read(SW_BOOTLD) and (test_fail == False) and not test_only):
                    # Need to reset board to throw into bootloader
                    # We also check the reset circuit is working correctly here
                    test_fail = sp_bootloader()
                    if test_fail == True:
                        fail_str = "RESET"
                    else:
                        test_fail = flash_circuitpython()

                # Check if we need to flash firmare / test code
                if (not io_read(SW_FIRMWARE) and (test_fail == False) and not test_only):
                    test_fail = flash_firmware()

                # Check if we need to test the DUT
                if (not io_read(SW_TEST) and (test_fail == False)):
                    sp_reset() # Need to power cut here
                    test_fail = serial_init()
                    if test_fail == True:
                        fail_str = "CDC2"
                        # Need to power cut here
                    else:
                        test_fail = test_dut(dut_type)
                    
                    # If we are just doing the final test, check the reset circuit
                    if (io_read(SW_BOOTLD) and io_read(SW_FIRMWARE) and (test_fail == False)) or (test_only and test_fail == False):
                        test_fail = sp_bootloader()
                        if test_fail == True:
                            fail_str = "RESET"
                        # Need to power cut here

                test_only = False
                # Advise user on how everything went
                if test_fail == False:
                    print(f'{Fore.GREEN}ALL STEPS PASSED!!!')
                    print(f"{Fore.YELLOW}Press YES for full test, NO for final test")
                    oled_write_dual("Test Passed!", "Y: FULL N: FINAL", size2 = 12)
                    retest = True
                    led_pass()
                    while True:
                        if (not io_read(SW_YES)):
                            break
                        if (not io_read(SW_NO)):
                            test_only = True
                            break
                elif test_fail == True:
                    print(f'{Fore.RED}TEST FAILED: {fail_str}')
                    print(f"{Fore.YELLOW}Press YES for full test, NO for final test")
                    oled_write_dual(f'FAIL: {fail_str}', "Y: FULL N: FINAL", size2 = 12)
                    retest = True
                    led_fail()
                    while True:
                        if (not io_read(SW_YES)):
                            break
                        if (not io_read(SW_NO)):
                            test_only = True
                            break
                break
        # except:
        #     print(f"{Fore.RED}Something went wrong, let's try again")
        #     break

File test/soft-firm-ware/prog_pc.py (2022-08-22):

#!/bin/python3

# Script to program and test sea-picro

import os
import time
import argparse
from colorama import Fore
import serial
from serial.tools import list_ports
import usb.core
import io
from multiprocessing import Process

bl_vid = 0x2e8a
bl_pid = 0x0003

cpy_vid = 0x6a6a
cpy_pid = 0x5350

TESTER_OKAY = 32
TESTER_ERROR = 33
TESTER_RESET = 34
HARD_RESET = 255

# Order is RST pins anticlockwise, then EXT pins anticlockwise
sp_pin_map = ["D0", "D1", "D2", "D3", "D4", "D5", "D6", "D7", "D8", "D9", "D21", "D23", "D20", "D22", "D26", "D27", "D28", "D29", "D12", "D13", "D14", "D15", "D16"]

def send_tester_string(string):
    tester_serial_io.write(str(string) + "\r\n")
    tester_serial_io.flush()

def get_tester_string():
    ret_str = tester_serial_io.readline()
    return ret_str

def send_dut_string(string):
    dut_serial_io.write(str(string) + "\r\n")
    dut_serial_io.flush()

def get_dut_string():
    ret_str = dut_serial_io.readline()[0:-1]
    return ret_str

def flash_circuitpython():
    ''' Flashes circuitpython firmware. '''
    test_fail = False

    found_rpi = False
    # Spinlock until RPi bootloader is found
    while found_rpi == False:
        dev = usb.core.find(find_all=1)
        for cfg in dev:
            if cfg.idVendor == bl_vid and cfg.idProduct == bl_pid:
                found_rpi = True
        time.sleep(1)

    time.sleep(3)
    print(f"{Fore.BLUE}RPi Bootloader found, copying CircuitPython")
    retval = os.system("cp circuitpy-sea-picro.uf2 /media/josh/RPI-RP2")
    if retval != 0:
        print(f'{Fore.RED}FAILED TO FLASH CPY !')
        test_fail = True

    return test_fail

def flash_firmware():
    ''' Flashes test firmware. '''
    test_fail = False
    found_cpy = False
    # Spinlock until circuitpython is found
    while found_cpy == False:
        dev = usb.core.find(find_all=1)
        for cfg in dev:
            if cfg.idVendor == cpy_vid and cfg.idProduct == cpy_pid:
                found_cpy = True
        time.sleep(1)

    print(f"{Fore.BLUE}CircuitPython found, copying test firmware")
    time.sleep(5)
    retval = os.system("cp -rf circuitpy-files/* /media/josh/CIRCUITPY")
    if retval != 0:
        print(f'{Fore.RED}FAILED TO FLASH TEST FW !')
        test_fail = True
    else:
        send_tester_string(HARD_RESET)

    return test_fail

def test_ident():
    # Check we have the right /dev/ttyACM port
    test_fail = False
    send_dut_string("ident")
    ret_str = get_dut_string()

    if ret_str == "ident = Sea-Picro!":
        print(f'{Fore.BLUE}IDENT passed')
    else:
        send_tester_string(TESTER_ERROR)
        print(f'{Fore.RED}IDENT Failed, possibly wrong /dev/ttyACM port')
        test_fail = True

    return test_fail

def test_vbus():
    # Check VBUS detection
    test_fail = False
    send_dut_string("vbus_test")
    ret_str = get_dut_string()

    if ret_str == "vbus = high":
        print(f'{Fore.BLUE}VBUS detect passed')
    elif ret_str == "vbus = low":
        send_tester_string(TESTER_ERROR)
        print(f'{Fore.RED}VBUS detect failed')
    else:
        send_tester_string(TESTER_ERROR)
        print(f'{Fore.RED}VBUS detect failed')
        test_fail = True

    return test_fail

def test_led():
    # RGB test time
    test_fail = False
    print(f'{Fore.YELLOW}Monitor LEDs please')
    send_dut_string("led_rgb")
    
    print(f'{Fore.YELLOW}Did LEDs cycle R/G/B? (Y)es / (N)o / (R)epeat{Fore.WHITE}')
    time.sleep(3)
    recv = input()

    if recv.lower() == "y":
        print(f'{Fore.BLUE}RGB LEDs passed')
        send_dut_string("led_rbw") # Party Time!
    elif recv.lower() == "n":
        send_tester_string(TESTER_ERROR)
        print(f'{Fore.RED}RGB LEDs failed')
        test_fail = True
    elif recv.lower() == "r":
        test_led()

    time.sleep(2)

    return test_fail

def test_keys(model):
    ''' Test all IO with test fixture.
    Transmit number according to pin location, which test fixture will pull low, simulating key press.
    DUT will then respond with a bitfield showing IO state. '''
    test_fail = False

    found_cpy = False
    # Spinlock until circuitpython is found
    while found_cpy == False:
        dev = usb.core.find(find_all=1)
        for cfg in dev:
            if cfg.idVendor == cpy_vid and cfg.idProduct == cpy_pid:
                found_cpy = True
        time.sleep(1)

    print("CircuitPython found, beginnig test")

    if model == "rst":
        num_io = 18 # RST has 18 IO
    if model == "ext":
        num_io == 23 # EXT has 23 IO

    for pos in range(1,num_io+1):
        send_tester_string(pos)
        time.sleep(0.02)
        send_dut_string("io_test")
        ret_str = get_dut_string()

        array = ret_str[1:-1].split(", ") # Convert to array of strings "True", "False"

        key_fail = False # Used to flag if a key passes it's test or not

        # Loop through array and check val = False unless index == pos
        for index in range(0,num_io):
            # Case where we expect a key to be pressed
            if index == pos-1:
                if array[index] == "True":
                    pass
                else:
                    send_tester_string(TESTER_ERROR)
                    print(f'{Fore.RED}{sp_pin_map[pos-1]}: IO {sp_pin_map[index]} was NOT pressed')
                    key_fail = key_fail or True
                    test_fail = True

            # Case where we do not expect a key to be pressed
            elif index != pos-1:
                if array[index] == "False":
                    pass
                else:
                    send_tester_string(TESTER_ERROR)
                    print(f'{Fore.RED}{sp_pin_map[pos-1]}: IO {sp_pin_map[index]} WAS pressed')
                    key_fail = key_fail or True
                    test_fail = True

        if not key_fail:
            print(f'{Fore.BLUE}{sp_pin_map[pos-1]}: IO {sp_pin_map[pos-1]} passed') # Print passed message if a fail message hasn't been printed


    return test_fail

def test_dut(model):

    test_fail = False

    test_fail = test_fail or test_ident()
    test_fail = test_fail or test_vbus()
    test_fail = test_fail or test_led()
    test_fail = test_fail or test_keys(model)

    return test_fail
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

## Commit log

2022-01-05 first pass
    [sea-picro.kicad_pcb, sea-picro.kicad_sch]
2022-01-05 add ws2812 3d model
    [sea-picro.kicad_pcb, sea-picro.kicad_sch]
2022-01-06 clean up traces and add BOM
    [sea-picro.kicad_pcb, sea-picro.kicad_sch]
2022-03-07 update dates and revision number
    [sea-picro.kicad_pcb, sea-picro.kicad_sch]
2022-03-07 0.2 layout wip
    [sea-picro.kicad_pcb, sea-picro.kicad_sch]
2022-03-07 sea picro footprint changes
2022-03-08 0.2 ready for review
    [sea-picro-bom.csv, sea-picro.kicad_pcb, sea-picro.kicad_sch]
2022-03-13 add USB D+- on pin header
    [sea-picro.kicad_pcb, sea-picro.kicad_sch]
2022-03-13 added version with extended pins, need to backport changes to reset button version
    [sea-picro.kicad_pcb, sea-picro.kicad_sch]
2022-03-14 split into rst and ext versionN
    [sea-picro-bom.csv, sea-picro.kicad_pcb, sea-picro.kicad_sch]
2022-03-14 update documentatiotn with latest updates
    [sea-picro-bom.csv, sea-picro.kicad_pcb, sea-picro.kicad_sch]
2022-03-15 add usb vbus detect
    [sea-picro-bom.csv, sea-picro.kicad_pcb, sea-picro.kicad_sch]
2022-03-18 add LED driver and more test points
    [sea-picro-bom.csv, sea-picro.kicad_pcb, sea-picro.kicad_sch]
2022-03-26 update vscore markings
    [BOM-sea-picro.csv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]
2022-04-15 update ldo caps to 1u
    [BOM-sea-picro.csv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]
2022-05-05 fixes after assembly
    [sea-picro-bom.csv, sea-picro.kicad_pcb, sea-picro.kicad_sch]
2022-05-08 fix lcsc pn typo
    [sea-picro-bom.csv, sea-picro.kicad_pcb, sea-picro.kicad_sch]
2022-06-18 0.2 errata fixes, need to review before oredering
    [sea-picro.kicad_pcb, sea-picro.kicad_sch]
2022-06-19 Remove Pin 12 message
    [sea-picro.kicad_pcb]
2022-06-20 clean up routing
    [sea-picro.kicad_pcb, sea-picro.kicad_sch]
2022-06-21 cleanup before ordering 0,3
    [sea-picro.kicad_pcb]
2022-06-23 sea picro footprint overhaul
    [sea-picro.kicad_pcb, sea-picro.kicad_sch]
2022-06-23 rst moved to new footprints, clean up ext
    [sea-picro.kicad_pcb, sea-picro.kicad_sch]
2022-06-24 add castellated r0.3, fix gnd pour
    [sea-picro.kicad_pcb, sea-picro.kicad_sch]
2022-06-25 update production outputs
    [sea-picro-bom.csv, sea-picro.kicad_pcb, sea-picro.kicad_sch]
2022-06-26 add teardrops and melted versions, update LDO MPN
    [sea-picro-bom.csv, sea-picro.kicad_pcb, sea-picro.kicad_sch]
2022-06-27 fix 1u cap bom
    [sea-picro-bom.csv, sea-picro.kicad_pcb, sea-picro.kicad_sch]
2022-07-15 simple test fixture
    [sea-picro.kicad_pcb, sea-picro.kicad_sch]
2022-07-15 wip test fixture schematic
    [sea-picro.kicad_pcb, sea-picro.kicad_sch]
2022-07-15 move pin 25 line above sp
2022-07-25 tester footprints setup
    [sea-picro.kicad_pcb, sea-picro.kicad_sch]
2022-07-28 release 1.0
    [sea-picro-bom.csv, sea-picro.kicad_pcb, sea-picro.kicad_sch]
2022-07-29 fix trace width for level shifter
    [sea-picro.kicad_pcb]
2022-07-30 rough mechanical layout
    [sea-picro.kicad_pcb, sea-picro.kicad_sch]
2022-08-18 update cpy test code
    [sea-picro.kicad_pcb]
2022-08-22 reset after fw to ensure cdc2 enumeration
    [prog_pc.py]
2022-10-12 shift reg and adc working
2022-10-15 tester functional, need to add oled and power switch
2022-10-16 update reset circuit
